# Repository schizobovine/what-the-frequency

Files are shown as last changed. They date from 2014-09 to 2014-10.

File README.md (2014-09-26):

What's the Frequency, Arduino?
==================

What The Frequency is an Arduino-compatible frequency counter with a 4040N to extend the measurement range. Based on the [SparkFun]() [Frequency Counter Kit](https://www.sparkfun.com/products/10140), which in turn is based on [FunCount](http://www.nuxie1.com/guides/funcount-frequency-counter.html) by Nuxie.

My original goal was to understand how/why the ground shunt capacitors are necessary when one includes a crystal oscillator as a clock for a microcontroller. I wanted to see if the calculations I was making based on load capacitance had any bearing at all on the circuit, and by how much.

Three herds of bald yaks later, this almost-but-not-quite circuit is what I have. So it goes.

My modifications include:
* 4040 12-bit binary ripple counter to extend the measurable range beyond 8MHz
* Shrink the LCD down a bit
* Size the PCB to fit a [Hammond 1591XXA enclosure](http://www.hammondmfg.com/dwg2XX.htm)
* DC barrel jack and voltage regulator
* Some kind of external probe (this was a terrible idea)

In the process, I've leared more than a bit about how oscillators work, PCB design, and just how little my CS education prepared me for electrical engineering. ;)

As it stands, the project is incomplete: in my haste to get a damn board back
from OSHPark, I didn't thoroughly think through the design. There's a single
external probe connection...and no ground. And that adding those would upset
the measurement by adding a ton of extra capacitance, enough to swamp the
difference between a 22pF and a 30pF cap.

So, in the interest of building something useable but still having a modicum of
accuracy, I'm going to be including another Atmel chip (likely the ATTiny84,
since the 85 has the clock output on the same pin as the input for running a
crystal osciallator circuit) to get a given crystal circuit oscillating. By
calibrating and measuring the capacitance (and then accounting for that), I
should be have a test harness for the typical Pierce oscillator setup that
seems to get used a lot.

Licensed under the same Creative Commons BY-NC-SA 3.0 license as the kit I was
basing it on (though it's pretty much completely diverged at this point). I've been using CC-BY-SA-4.0 since I don't give a crap if you make money off this or not. Honestly, if you're using my board designs and selling them to people,
1. You're an idiot
2. You're gonna get sued when someone catches on fire (probably an orphanage)
3. I DISCLAIM ALL LIABILITY FOR THE USE OF THIS. USE AT YOUR OWN RISK.

YMMV, check with your doctor before taking Frequenizole, etc.

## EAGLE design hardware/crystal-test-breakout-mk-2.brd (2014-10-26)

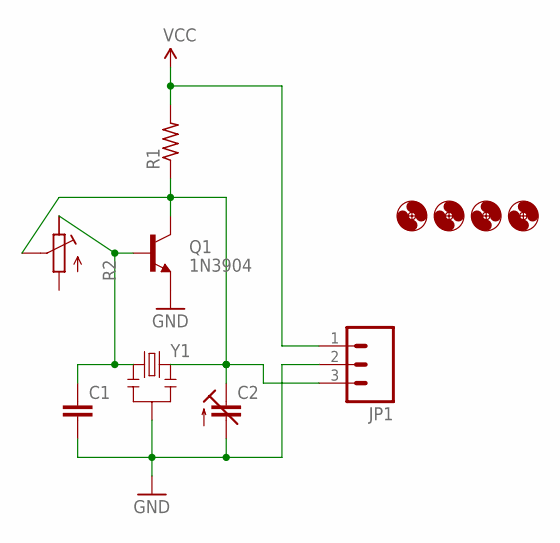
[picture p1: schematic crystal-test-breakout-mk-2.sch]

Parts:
C1: CAPACITOR-CERAMIC025-025X050; C025-025X050
C2: CAPACITOR-TRIM3040.427; CTRIM3040.427
H1, H2, H3, H4: HOLE#2; HOLE-#2
JP1: M03PTH; 1X03
Q1: 1N3904; TO-92-AMMO
R1: RESISTORPTH-AXIAL-5.08MM; RESISTOR-AXIAL-PTH-5.08MM
R2: POTENTIOMETER3296W; RTRIM3296W
Y1: RESONATORPTH-BIGHOLES; RESONATOR-PTH-BIGHOLES

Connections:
GND: C1.2, C2.2 (A), JP1.2, Q1.1 (E), Y1.2
unnamed: C1.1, Q1.2 (B), R2.3 (E), Y1.1
unnamed: C2.1A (E), C2.1B (E), JP1.3, Q1.3 (C), R1.P$1 (1), R2.2 (S), Y1.3
VCC: JP1.1, R1.P$2 (2)

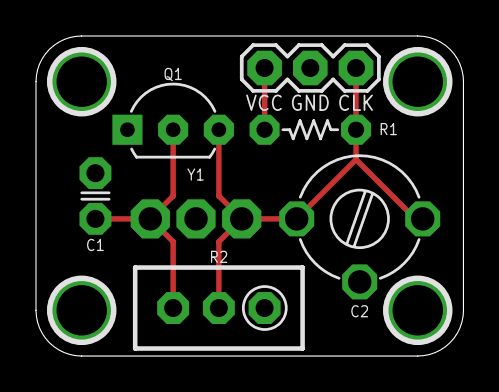
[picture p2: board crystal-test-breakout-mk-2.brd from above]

Board: 2 copper layers, 23.7 x 17.8 mm, 12 parts (1 on the bottom side), 4 nets.

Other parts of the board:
U$1: CC-BY-SA-4.0-NO-URL

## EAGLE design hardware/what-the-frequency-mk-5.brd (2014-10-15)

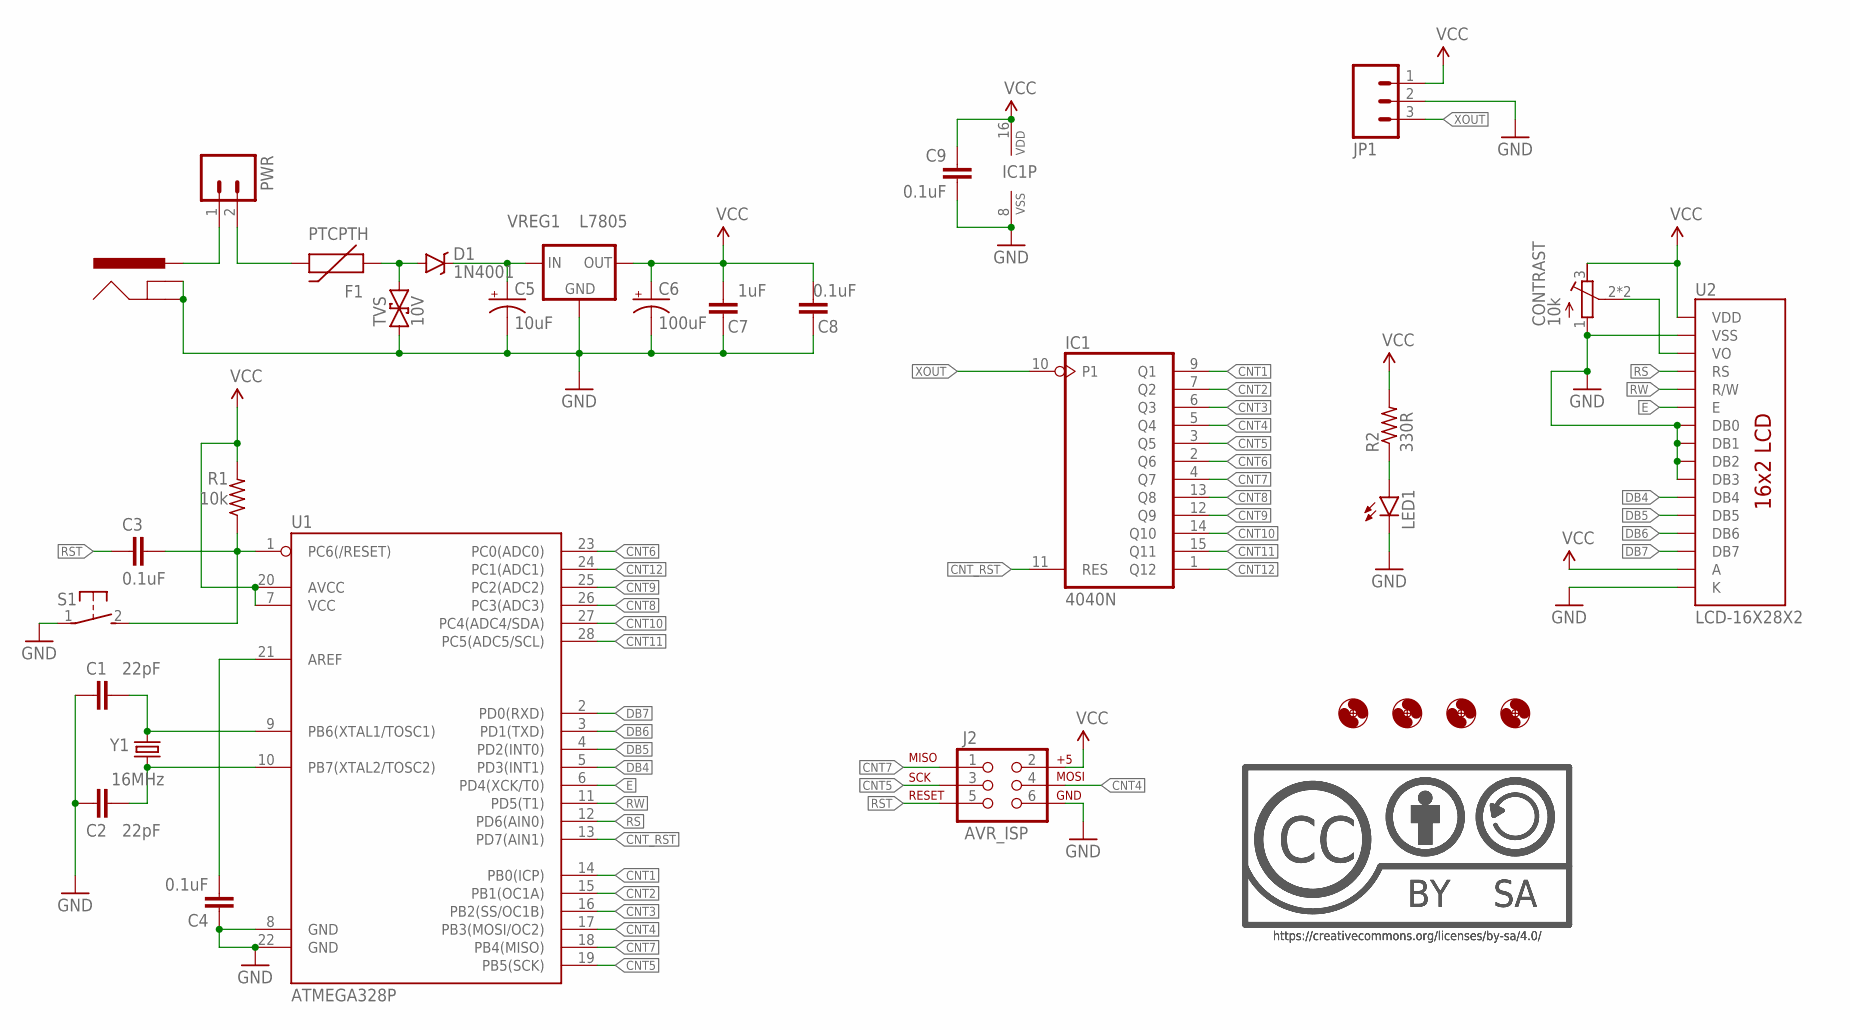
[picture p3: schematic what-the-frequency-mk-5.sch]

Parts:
C1, C2: 22pF; C025-024X044
C3, C4, C8, C9: 0.1uF; C025-024X044
C5: 10uF; E2-5
C6: 100uF; E2,5-6
C7: 1uF; C025-024X044
CONTRAST: 10k; POT-THUMBWHEEL
D1: 1N4001; DO-41
F1: PTCPTH; PTC
H1, H2, H3, H4: HOLE#4; HOLE-#4
IC1: 4040N; DIL16
J1: POWER_JACKPTH; POWER_JACK_PTH
J2: AVR_ISP; AVR_MINI_PROG
JP1: M03PTH; 1X03
LED1: LED3MM
PWR: M02PTH; 1X02
R1: 10k; RESISTOR-AXIAL-PTH-7.68MM
R2: 330R; RESISTOR-AXIAL-PTH-6.35MM
S1: DTS-3
TVS: 10V; DO-41-TVS
U1: ATMEGA328P; DIL28-3
U2: LCD-16X28X2; LCD-8X2
U$3, U$7: CC-BY-SA-4.0NO-URL; CC-BY-SA-4.0-NO-URL
VREG1: L7805; TO220V
Y1: 16MHz; HC49U-V

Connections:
CNT1: IC1.9 (Q1), U1.14 (PB0(ICP))
CNT2: IC1.7 (Q2), U1.15 (PB1(OC1A))
CNT3: IC1.6 (Q3), U1.16 (PB2(SS/OC1B))
CNT4: IC1.5 (Q4), J2.4, U1.17 (PB3(MOSI/OC2))
CNT5: IC1.3 (Q5), J2.3, U1.19 (PB5(SCK))
CNT6: IC1.2 (Q6), U1.23 (PC0(ADC0))
CNT7: IC1.4 (Q7), J2.1, U1.18 (PB4(MISO))
CNT8: IC1.13 (Q8), U1.26 (PC3(ADC3))
CNT9: IC1.12 (Q9), U1.25 (PC2(ADC2))
CNT10: IC1.14 (Q10), U1.27 (PC4(ADC4/SDA))
CNT11: IC1.15 (Q11), U1.28 (PC5(ADC5/SCL))
CNT12: IC1.1 (Q12), U1.24 (PC1(ADC1))
CNT_RST: IC1.11 (RES), U1.13 (PD7(AIN1))
DB4: U1.5 (PD3(INT1)), U2.11 (DB4)
DB5: U1.4 (PD2(INT0)), U2.12 (DB5)
DB6: U1.3 (PD1(TXD)), U2.13 (DB6)
DB7: U1.2 (PD0(RXD)), U2.14 (DB7)
E: U1.6 (PD4(XCK/T0)), U2.6 (E)
GND: C1.2, C2.2, C4.1, C5.-, C6.-, C7.1, C8.1, C9.1, CONTRAST.1 (A), IC1.8 (VSS), J1.GND, J1.GNDBREAK, J2.6, JP1.2, LED1.K (C), S1.1, TVS.P$1 (1), U1.8 (GND), U1.22 (GND), U2.1 (VSS), U2.7 (DB0), U2.8 (DB1), U2.9 (DB2), U2.10 (DB3), U2.16 (K), VREG1.2 (GND)
unnamed: C5.+, D1.C, VREG1.1 (IN)
unnamed: LED1.A, R2.P$1 (1)
unnamed: J1.PWR, PWR.1
unnamed: D1.A, F1.P$1 (1), TVS.P$2 (2)
unnamed: F1.P$2 (2), PWR.2
unnamed: C1.1, U1.9 (PB6(XTAL1/TOSC1)), Y1.2
unnamed: C2.1, U1.10 (PB7(XTAL2/TOSC2)), Y1.1
unnamed: C4.2, U1.21 (AREF)
unnamed: CONTRAST.2 (S), CONTRAST.2@1 (S), U2.3 (VO)
unnamed: C3.2, R1.P$1 (1), S1.2, U1.1 (PC6(/RESET))
RS: U1.12 (PD6(AIN0)), U2.4 (RS)
RST: C3.1, J2.5
RW: U1.11 (PD5(T1)), U2.5 (R/W)
VCC: C6.+, C7.2, C8.2, C9.2, CONTRAST.3 (E), IC1.16 (VDD), J2.2, JP1.1, R1.P$2 (2), R2.P$2 (2), U1.7 (VCC), U1.20 (AVCC), U2.2 (VDD), U2.15 (A), VREG1.3 (OUT)
XOUT: IC1.10 (P1), JP1.3

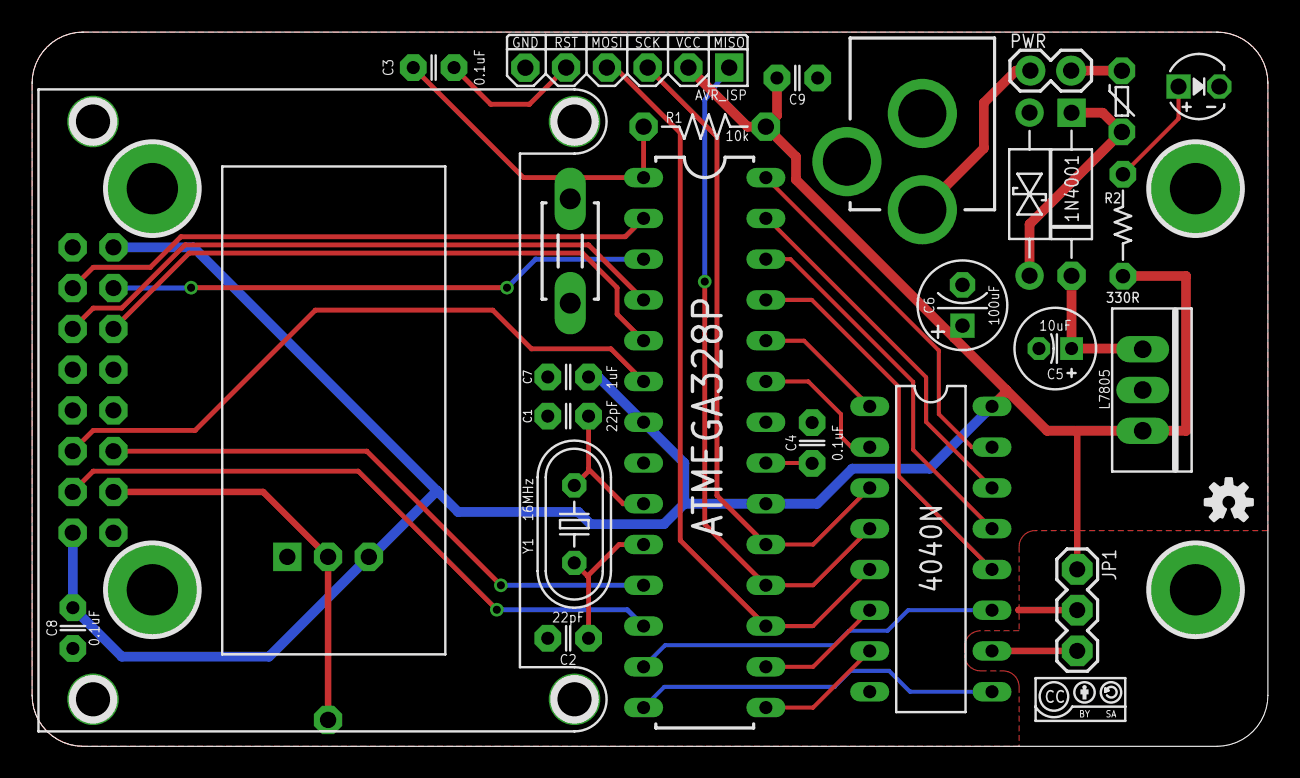
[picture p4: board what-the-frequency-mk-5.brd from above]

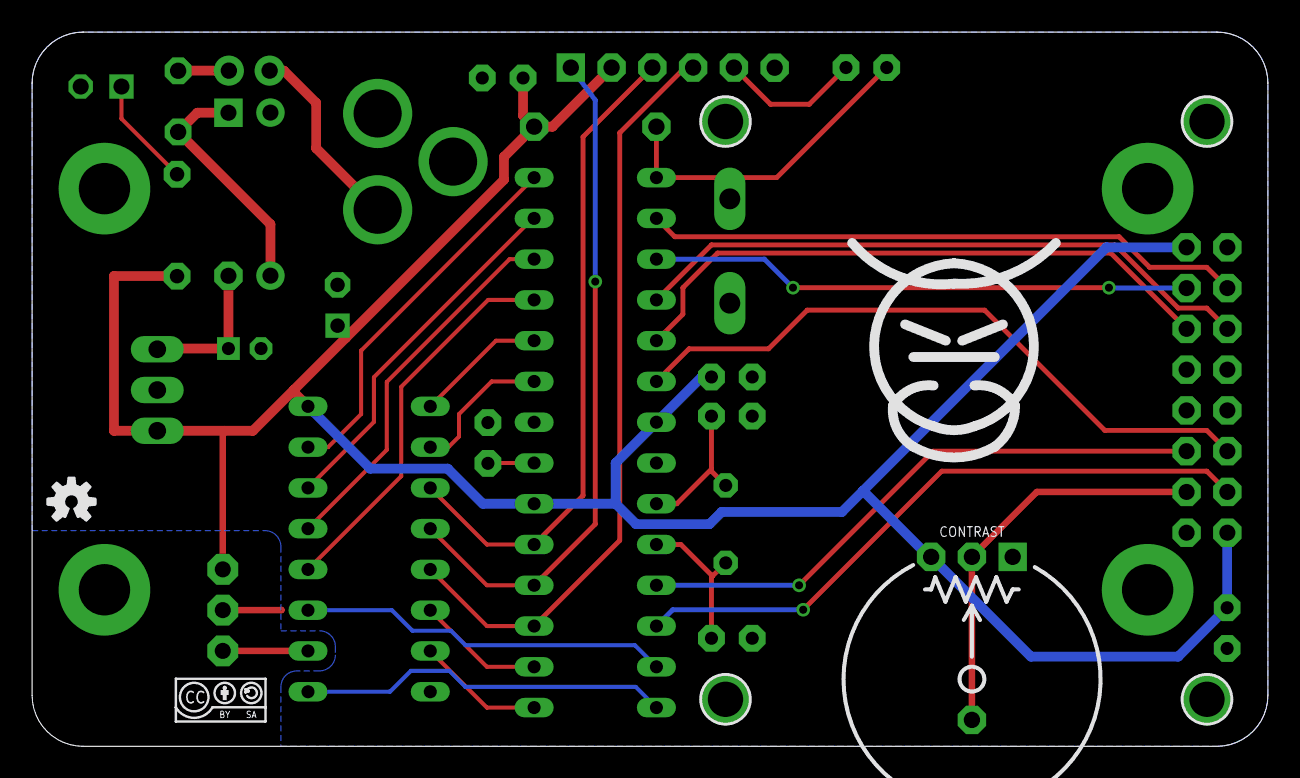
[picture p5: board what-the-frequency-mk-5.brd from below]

Board: 2 copper layers, 77.0 x 44.5 mm, 35 parts (4 on the bottom side), 34 nets.

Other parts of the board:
U$2, U$4: OSHW-LOGO-S
U$8: COW

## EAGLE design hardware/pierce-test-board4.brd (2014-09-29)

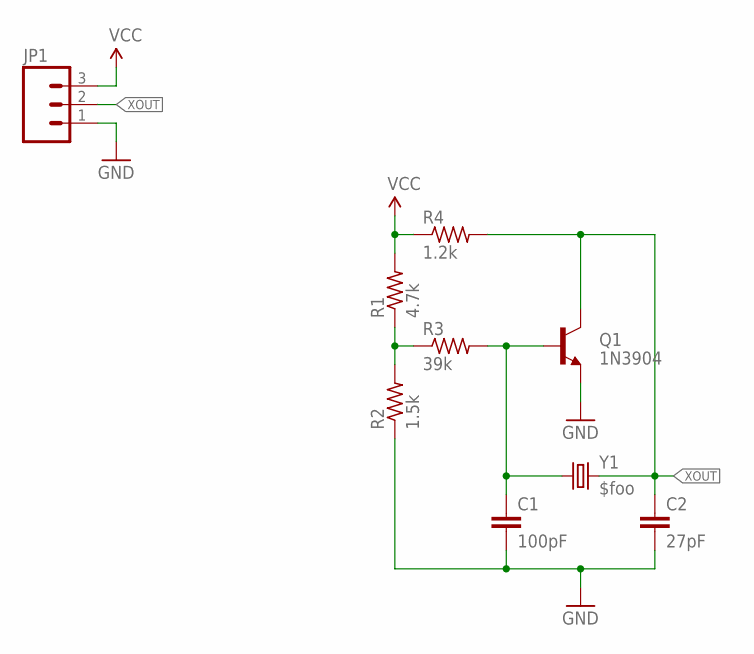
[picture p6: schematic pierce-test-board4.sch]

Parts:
C1: 100pF; C025-024X044
C2: 27pF; C025-024X044
JP1: M03PTH; 1X03
Q1: 1N3904; TO-92-AMMO
R1: 4.7k; RESISTOR-AXIAL-PTH-5.08MM
R2: 1.5k; RESISTOR-AXIAL-PTH-5.08MM
R3: 39k; RESISTOR-AXIAL-PTH-5.08MM
R4: 1.2k; RESISTOR-AXIAL-PTH-5.08MM
Y1: $foo; HC49U-V

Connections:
GND: C1.2, C2.2, JP1.1, Q1.1 (E), R2.P$1 (1)
unnamed: R1.P$1 (1), R2.P$2 (2), R3.P$1 (1)
unnamed: C1.1, Q1.2 (B), R3.P$2 (2), Y1.1
VCC: JP1.3, R1.P$2 (2), R4.P$1 (1)
XOUT: C2.1, JP1.2, Q1.3 (C), R4.P$2 (2), Y1.2

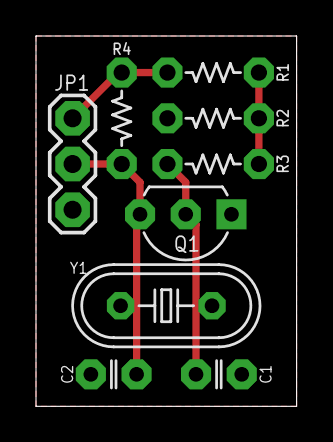
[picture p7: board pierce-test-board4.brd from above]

Board: 2 copper layers, 14.5 x 20.6 mm, 10 parts (1 on the bottom side), 5 nets.

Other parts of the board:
U$1: CC-BY-SA-4.0-NO-URL

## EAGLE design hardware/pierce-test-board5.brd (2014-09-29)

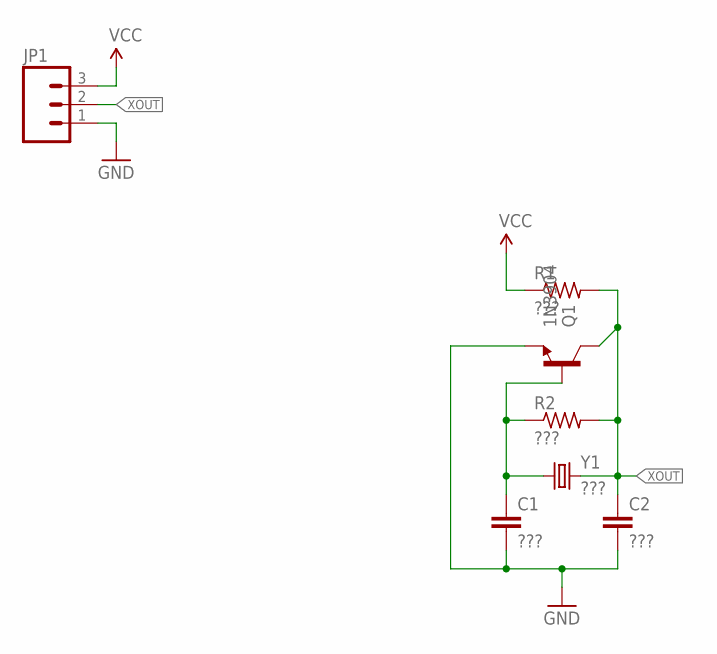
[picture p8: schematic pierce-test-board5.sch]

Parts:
C1, C2: ???; C025-024X044
JP1: M03PTH; 1X03
Q1: 1N3904; TO-92-AMMO
R1, R2: ???; RESISTOR-AXIAL-PTH-5.08MM
Y1: ???; HC49U-V

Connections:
GND: C1.2, C2.2, JP1.1, Q1.1 (E)
unnamed: C1.1, Q1.2 (B), R2.P$1 (1), Y1.1
VCC: JP1.3, R1.P$1 (1)
XOUT: C2.1, JP1.2, Q1.3 (C), R1.P$2 (2), R2.P$2 (2), Y1.2

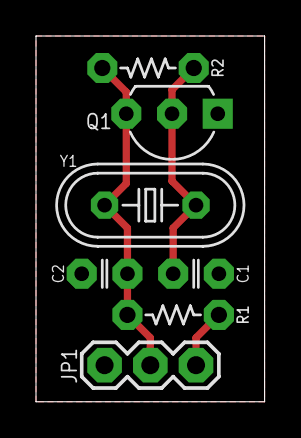
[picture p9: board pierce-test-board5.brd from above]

Board: 2 copper layers, 12.7 x 20.3 mm, 8 parts (1 on the bottom side), 4 nets.

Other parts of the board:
U$1: CC-BY-SA-4.0-NO-URL

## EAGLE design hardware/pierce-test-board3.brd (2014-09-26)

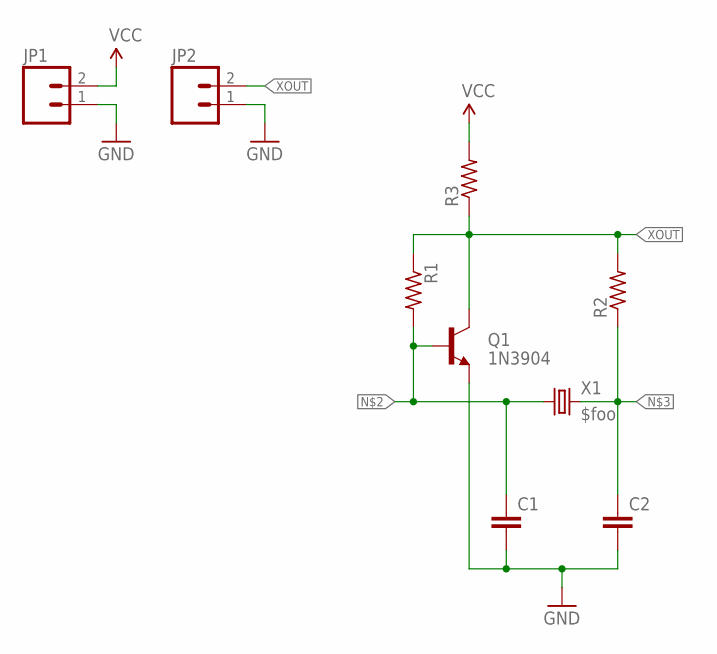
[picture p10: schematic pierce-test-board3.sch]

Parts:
C1, C2: CAPACITOR-CERAMIC025-024X044; C025-024X044
JP1, JP2: M02PTH; 1X02
Q1: 1N3904; TO-92-AMMO
R1, R2, R3: RESISTORPTH-AXIAL-5.08MM; RESISTOR-AXIAL-PTH-5.08MM
X1: $foo; HC49U-V

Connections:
GND: C1.2, C2.2, JP1.1, JP2.1, Q1.1 (E)
unnamed: C1.1, Q1.2 (B), R1.P$2 (2), X1.1
unnamed: C2.1, R2.P$1 (1), X1.2
VCC: JP1.2, R3.P$2 (2)
XOUT: JP2.2, Q1.3 (C), R1.P$1 (1), R2.P$2 (2), R3.P$1 (1)

Board: 2 copper layers, 9 parts (0 on the bottom side), 5 nets, no tracks yet.

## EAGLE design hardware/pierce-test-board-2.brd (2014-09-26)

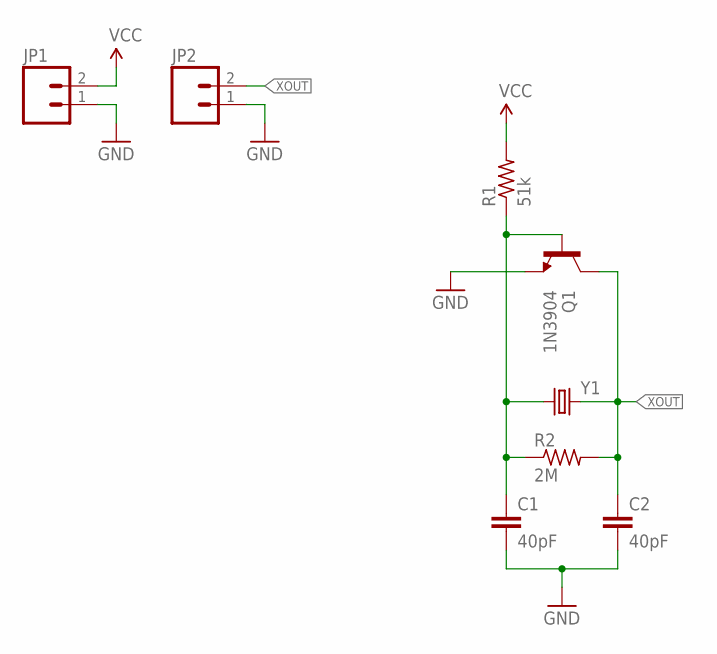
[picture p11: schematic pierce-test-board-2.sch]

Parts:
C1, C2: 40pF; C025-024X044
JP1, JP2: M02PTH; 1X02
Q1: 1N3904; TO-92-AMMO
R1: 51k; RESISTOR-AXIAL-PTH-7.68MM
R2: 2M; RESISTOR-AXIAL-PTH-7.68MM
Y1: CRYSTALHC49UV; HC49U-V

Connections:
GND: C1.2, C2.2, JP1.1, JP2.1, Q1.1 (E)
unnamed: C1.1, Q1.2 (B), R1.P$1 (1), R2.P$1 (1), Y1.1
VCC: JP1.2, R1.P$2 (2)
XOUT: C2.1, JP2.2, Q1.3 (C), R2.P$2 (2), Y1.2

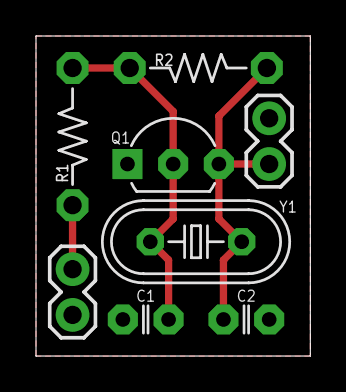
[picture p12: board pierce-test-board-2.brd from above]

Board: 2 copper layers, 15.2 x 17.8 mm, 9 parts (1 on the bottom side), 4 nets.

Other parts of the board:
U$1: CC-BY-SA-4.0-NO-URL

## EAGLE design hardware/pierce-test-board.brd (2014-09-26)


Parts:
C1, C2: CAPACITOR-CERAMIC025-024X044; C025-024X044
JP1, JP2: M02PTH; 1X02
Q1: TRANSISTOR_NPNTO-92-AMMO-EBC; TO-92-AMMO
R1, R2: RESISTORPTH-AXIAL-5.08MM; RESISTOR-AXIAL-PTH-5.08MM
Y1: CRYSTALHC49UV; HC49U-V

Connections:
GND: C1.2, C2.2, JP1.1, JP2.1, Q1.1 (E), R2.P$1 (1)
unnamed: C1.1, Q1.2 (B), R1.P$1 (1), R2.P$2 (2), Y1.1
VCC: JP1.2, R1.P$2 (2)
XOUT: C2.1, JP2.2, Q1.3 (C), Y1.2

Board: 2 copper layers, 8 parts (0 on the bottom side), 4 nets, no tracks yet.

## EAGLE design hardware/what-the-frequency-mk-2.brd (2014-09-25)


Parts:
C1, C2, C5, C8: 0.1uF; C025-024X044
C3, C4: 22pF; C025-024X044
C6: 10uF; E2,5-5
C7: 100uF; E2,5-5
CONTRAST: POTENTIOMETERTHUMBWHEEL-16MM; POT-THUMBWHEEL
D1: 1N4001; DO-41
F1: PTCPTH; PTC
FTDI: FTDI_BASICPTH-TINY-TEXT; FTDI_TINY_TXT
IC1: 4040N; DIL16
J1: POWER_JACKPTH; POWER_JACK_PTH
LED1: LED3MM
PROBE_JACK: BANANA_CONNPTH-RA; BANANA-PTH-RA-SAFEWORD
R1: 10k; AXIAL-PTH-5.08MM
R2: 330R; AXIAL-PTH-5.08MM
S1: SWITCH-MOMENTARY-2PTH-RA; TACTILE-PTH-SIDE
SW1, SW2: M01PTH_2MM; 1X01_2MM
TVS: 10V; DO-41-TVS
TVS1: 39V; DO-41-TVS
U2: LCD-16X28X2; LCD-8X2
U3: ATMEGA328P; DIL28-3
VREG1: L7805; TO-92-AMMO
Y1: 16MHz; HC49U-V

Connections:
COUNT_RST: IC1.11 (RES), U3.15 (PB1(OC1A))
DB4: U2.11 (DB4), U3.23 (PC0(ADC0))
DB5: U2.12 (DB5), U3.24 (PC1(ADC1))
DB6: U2.13 (DB6), U3.25 (PC2(ADC2))
DB7: U2.14 (DB7), U3.26 (PC3(ADC3))
E: U2.6 (E), U3.28 (PC5(ADC5/SCL))
GND: C2.1, C3.2, C4.2, C5.1, C6.-, C7.-, C8.1, CONTRAST.1 (A), FTDI.CTS (5), FTDI.GND (6), IC1.8 (VSS), J1.GND, J1.GNDBREAK, LED1.K (C), S1.1, TVS.P$1 (1), TVS1.P$1 (1), U2.1 (VSS), U2.16 (K), U3.8 (GND), U3.22 (GND), VREG1.2 (GND)
MISO: U3.18 (PB4(MISO))
MOSI: U3.17 (PB3(MOSI/OC2))
unnamed: C6.+, D1.C, VREG1.1 (IN)
unnamed: LED1.A, R2.P$1 (1)
unnamed: J1.PWR, SW1.1
unnamed: D1.A, F1.P$1 (1), TVS.P$2 (2)
unnamed: F1.P$2 (2), SW2.1
unnamed: C4.1, U3.9 (PB6(XTAL1/TOSC1)), Y1.2
unnamed: C3.1, U3.10 (PB7(XTAL2/TOSC2)), Y1.1
unnamed: C2.2, U3.21 (AREF)
unnamed: CONTRAST.2 (S), CONTRAST.2@1 (S), U2.3 (VO)
unnamed: C1.2, R1.P$1 (1), S1.2, U3.1 (PC6(/RESET))
PROBE: IC1.10 (P1), PROBE_JACK.P$1, PROBE_JACK.P$2, TVS1.P$2 (2)
RESET: C1.1, FTDI.DTR (1)
RS: U2.4 (RS), U3.27 (PC4(ADC4/SDA))
RW: U2.5 (R/W)
RX: FTDI.RXI (2), U3.2 (PD0(RXD))
SCK: U3.19 (PB5(SCK))
TX: FTDI.TXO (3), U3.3 (PD1(TXD))
VCC: C5.2, C7.+, C8.2, CONTRAST.3 (E), FTDI.VCC (4), IC1.16 (VDD), R1.P$2 (2), R2.P$2 (2), U2.2 (VDD), U2.15 (A), U3.7 (VCC), U3.20 (AVCC), VREG1.3 (OUT)

Board: 2 copper layers, 27 parts (1 on the bottom side), 23 nets, no tracks yet.

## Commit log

2014-09-25 newer revisions of the board, including the first one sent for fabrication
    [what-the-frequency-mk-2.brd, what-the-frequency-mk-2.sch, what-the-frequency-mk-3.brd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]
2014-09-25 start of mark 4 board to include clock driving circuit
    [what-the-frequency-mk-4.brd, what-the-frequency-mk-4.sch]
2014-09-26 test oscillator PCBs
    [pierce-test-board-2.brd, pierce-test-board-2.sch, pierce-test-board.brd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]
2014-09-26 some more test osc boards
    [pierce-test-board3.brd, pierce-test-board3.sch, pierce-test-board4.brd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]
2014-09-29 MOAR BOARDS FOR THE BOARD THRONE
    [crystal-test-breakout.brd, crystal-test-breakout.sch, pierce-test-board5.brd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]
2014-09-29 yet another test pcb
    [pierce-test-board4.brd, pierce-test-board4.sch]
2014-09-29 putting trimpot on its side for less whoopsy-daisy factor
    [crystal-test-breakout.brd, crystal-test-breakout.sch]
2014-10-15 new breakout for larger form factor varicap
    [crystal-test-breakout-mk-2.brd, crystal-test-breakout-mk-2.sch]

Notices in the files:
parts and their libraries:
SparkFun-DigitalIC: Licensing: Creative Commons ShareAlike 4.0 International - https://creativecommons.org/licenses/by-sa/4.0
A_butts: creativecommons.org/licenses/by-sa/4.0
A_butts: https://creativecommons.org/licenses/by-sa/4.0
